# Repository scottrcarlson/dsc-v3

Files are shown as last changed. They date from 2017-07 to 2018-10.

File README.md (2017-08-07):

# DSCv3

[What is Dirt Simple Comms (DSC) ?]
------------------

[Goals]
----------------
 1. To not require existing infrastructure
 2. To operate well and propage messages in poor rf environments.
 3. To securely exchange messages with friends in hostile rf environments. 
 4. To avoid central points of control in the system design.
 5. To keep the attack surface as small as possible.
 6. Make it easy to use and hard to mess up.
 7. To leak as little data as possible.
 8. Low Cost / Low Power / Long Range
 9. Small Form Factor / Portable
 10. Utilize LoRA Modulated 900mhz Radio System

[Bill of Materials]
------------------
(Work in Progress)
(Prices can be optimized based on source and quantity)
Total Estimated price $85-$120)

* $5 RPi Zero (Wherever you can get one)
* $13 DS3231 Precision RTC https://www.adafruit.com/product/3013
* $33 LL-RXR-27 LoRa Transceiver http://www.futureelectronics.com/en/Technologies/Product.aspx?ProductID=LLRXR27915SYMALINKLABS5062354&IM=0
* $23 OLED Bonnet https://www.digikey.com/products/en?mpart=3531&v=1528
* $3 SMA to u.Fl Adapter Cable https://www.amazon.com/2pcs-Female-Pigtail-Hirose-0-81mm/dp/B00UTT8842
* $13 Antenna 1/2 Wave 5dBi https://www.amazon.com/TECHTOO-700-2600Mhz-Directional-Connector-Wireless/dp/B00VV63WEI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
* OR
* $7 Antenna 1/2 Wave 5dBi https://www.amazon.com/915Mhz-antenna-direction-folding-Shipping/dp/B072QB7LRJ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
* RGB Led (tbd)
* Vibration (Disc Motor) (tbd)
* LiPo 2200mAh https://www.adafruit.com/product/328
* LiPo Charging/Switchover https://www.adafruit.com/product/1944

[Assembly / Wiring]
------------------

[Configuring Vanilla Raspian]
------------------

[Install DSCv3 Software]
------------------

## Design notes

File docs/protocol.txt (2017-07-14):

Dirt Simple Comms v2 (DSCv2) Messaging Device Description

[Table of Contents]
-------------------
 *- Goals
 *- Basic Description of Operation
 *- Facts
 *- Key Generation, Management and Exchange
 *- Authentication / Data Storage 
 *- Protocol Description: Messages
 *- Protocol Description: Beacons
 *- Future Work

[Goals]
----------------
 1. To not require existing infrastructure
 2. To operate well and propage messages in poor rf environments.
 3. To securely exchange messages with friends in hostile rf environments. 
 4. To avoid central points of control in the system design.
 5. To keep the attack surface as small as possible.
 6. Make it easy to use and hard to mess up.
 7. To leak as little data as possible.
 8. Low Cost / Low Power / Long Range
 9. Small Form Factor / Portable
 10. Utilize LoRA Modulated 900mhz Radio System

[Basic Description of Operation]
--------------------------------
A group of friends meet on location (camping, festivals, conferences, etc). Each person
produces their dscv2 module and generates two pairs of keys (encryption / signature keys) 
and exchanges their public keys physically (currently via USB).

The network is manually configured for fixed/static TDMA operation.

Now friends can freely exchange messages with each other. Every node acts as a repeater.
Every message gets repeated by all nodes. It is a blind broadcast. There is no routing
information or packet headers. All data is encrypted and then signed before transmission.
The idea is for all msgs to eventually get to where they are destined without sharing
too much meta data. 

If Alice wants to send a msg to Bob and they are not currently within range, other nodes 
that are may then receive the message, verify its signature and then begin repeating, 
eventually Bob receives his message.

All nodes will periodically broadcast a beacon, which is comprised of a cleartext hash that
is signed. 

Beacons Provide:
1. Signature
2. Repeat List Hash (Additional state info (EMPTY/QUIET)
3. Stats (Last seen, RSSI and SNR) <-- Indirectly

As the messages begin to pile up in each of the nodes repeat buffers, you can imagine the
network becomes more lethargic. To mitigate this an additional piece of information is
sent with the beacon. A hash of all msgs in the repeat buffer.

Each node tracks the last received beacon hash of its neighbors. If the hash is equal to
the current node, then a confidence counter is incremented. If all neighbors have a high level
of confidence (that everybody has everything), then the node will transition into a /quiet mode/.

Quiet mode prevents any further transmission of messages. It also increases the frequency of
beacon broadcasts. When in quiet mode, a special hash(quiet hash) is used. If a neighboring node
receives this quiet hash it will force that node into quiet mode as well. Quiet mode should 
propogate to all nodes. When all nodes exist the quiet mode period (typically 2 TDMA cycles),
the network is reset with empty repeat buffers.

Rinse, Repeat and Msg.

This system may shine at locations where there is no cellular service, or hostile actors 
running rampant over the rf spectrum.

[Facts]
--------------
1. A node can only know for certain that a msg is/or is NOT for them. Not whom it is destined.
2. A node can know the origination of a message (based on its signature)
3. A node can NOT know if a specific msg has arrived at its destination.
4. A node can know if EVERYONE has EVERYTHING. (Hence knowing a message has arrived at its dest)
5. A node will drop any packet that is not signed by its peers.

[Key Generation, Management and Exchange]
-----------------------------------------
 Key Generation Process Consists:
     1. Create Keychains
     2. Generating Pub/Priv Encyption Keys
     3. Generating Pub/Priv Signature Keys
     4. Encrypt each keychain with a randomly generated passphrase
     5. Store passphrases on yubikey/usb drive.
     ** Plans to move to U2F dongles, no static passwords!!

The public keys are then copied to every node on the network. Currently a valid signature
is required for a node to repeat a message. In this case we need to exchange 2*(n-1) keys 
to function properly. There is also a weakness as the origination of a msg is known to all. 
(But not the destination!) 

The keys are currently transferred on physical medium (usb drive), but should ultimately
be able to exchange over the air. 

[Authentication / Data Storage]
-------------------------------
All data is encrypted on disk. Cleartext only resides in memory. To authenticate
is to unencrypt the node's keychain. This happens by plugging in the yubikey device and long
pressing the button (which feeds a passphrase). If the correct yubikey is inserted, 
the keychain unlocks, and the current message threads are decrypted and ready for viewing. 
Once the key is removed, the screen locks, and memory is wiped. The system is now at rest. 
It is unable to decrypt or sign msgs. If physically stolen, no message data is available.

[Protocol Description]
------------------------------
Fixed TDMA stategy is used. Each node needs to be manually configured ahead of time.
The following settings are configurable:
    1. TDMA Slot Number
    2. Total Number of Nodes
    3. TX Time
    4. Deadband Time
Where the TDMA Slot Width = TX Time + Deadband Time

** Messages
----------
The cleartext max size is 150bytes (<-- what is the actual number)

Encypting and then signing the cleartext yields:

   cypher    signature
|[261 bytes][261 bytes]|

    * 255 bytes due to pkcs11 padding and 2048 bit key
    * 6 bytes are overhead from Keyczar library implementation. (***add details)

The total data packet size 522 bytes exceeds max rf packet size of 255 bytes. 

We must split the packet into 3 segments, and send them OTA individually:

   cipher    signature           Seg1          Seg2          Seg3
|[261 bytes][261 bytes]| --> |[255 bytes]| |[255 bytes]| |[12 bytes]|

The last 6 bytes of the cipher block get shifted into the beginning of the signature
block, the last 12 bytes of the signature block shifts into the third segment.

To help the packets get reassembled properly on the other end, the first 100 bytes 
are copied from Seg1 and Seg2 and appended to the third segment. The third segment will 
be called the fingerprint. (**is there a standard term for this)

    Seg1          Seg2       Fingerprint
|[255 bytes]| |[255 bytes]| |[212 bytes]|

Upon receiving each segment, the node will accumulate them into a temporary 
buffer that gets cleared periodically (to mitigate spam and orphan segments).
To reassemble we look for segments that are 212 bytes, and then use the two 100byte 
segments to search for the remaining subpackets in the buffer.
Once found and reassembled it removes the segments from the buffer and 
attempts to verify the signature of the complete packet.

Once the packet signature has been verfied, it is then added to the repeat buffer 
to be retransmitted to other nodes. If the node is /unlocked/ it will then attempt to
decrypt the packet. Upon success it is then further processed for viewing/storage.

Duplicate Segments and Messages are Dropped. Unsigned Packets get Dropped.

** BEACONS
----------
Beacon messages will play a large role in the health of the network. By exchanging state
information, each node can determine when all neighbors have all information. A beacon
is sent at the beginning of a nodes TDMA window.

Beacon Message:

   hash     signature
|[32 bytes][261 bytes]|

The repeat buffer of each node is hashed before transmitting the beacon. 

Each node tracks the state of its neighbors. When their hashes match a confidence counter
increments. Once any single node has a high confidence count on every node, a consensus
is made. (First to discover, Everyone has everything). The consensus triggers /Quiet/
mode. 

/Quiet/ mode prevents transmission of messages for a period of time. During this period of
time it sends a beacon continuously within its tdma slot.
The beacon contains a /Quiet/ hash, telling the other
nodes that it has decided that everyone has everything and therefore force peer nodes that 
receive this packet to also go into quiet mode. This mode propogates throughout the network,
and at the end of quiet mode the repeat list is cleared, and the system starts fresh.
** Note current issues. Race conditions....

[Future Work]
-------------
1. How to mitigate the damage a compromised node can do to a network.
	(spam/garbage with proper signature, breaking tdma transmit ediquite)
2. Rethink Keys / Key Exchange / Crypto. Try to make it simpler to use and to allow
	more features, such as forward secrecy, future secrecy, key exchange OTA,
	symettric network session keys to allow for sending one to many without sending n-1
	individually encrypted msgs.
3. Encrypt/Sign Beacons (Currently the beacon is cleartext + sig)
4. Dynamic TDMA (Adding/Removing Nodes, optimizing slot cycles based on presence)
5. Explore physical device hardening. (Tamper evident, Self Destruct, Proper Memory Handling,
	Trusted Computing)
6. External IC for RNG
7. Smaller formfactor / better UX
8. Replace static storage of keychain passphrase with decentralized U2F hardware key.

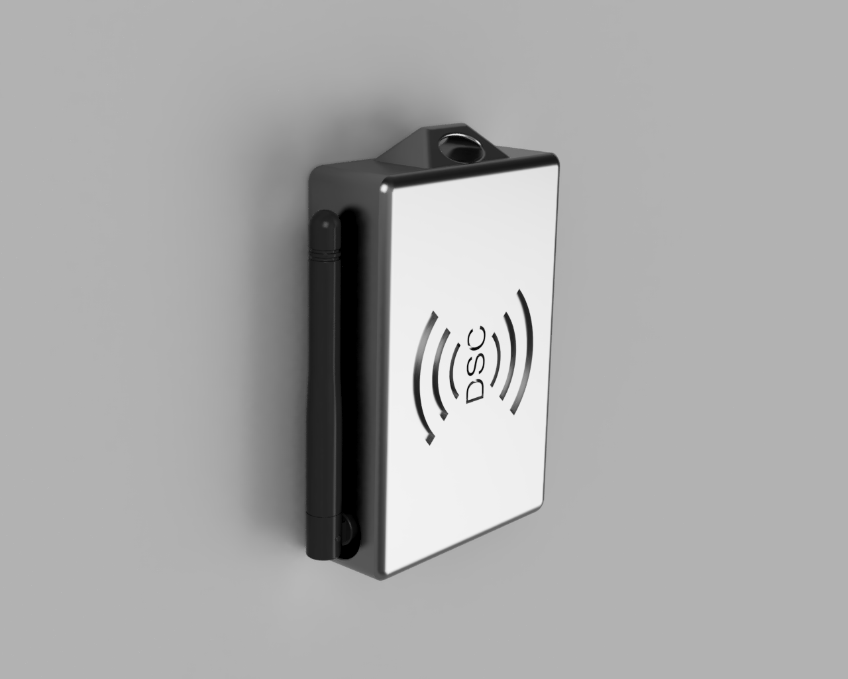
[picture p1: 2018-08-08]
enclosure/87cbd582-e5d6-46ba-be8c-0ddc85d05ea8.PNG

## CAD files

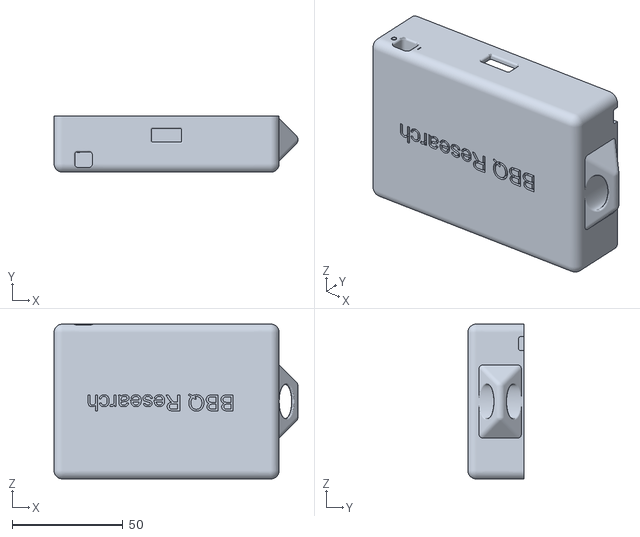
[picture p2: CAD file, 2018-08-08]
enclosure/Case.obj
110.1 x 25.4 x 69.8

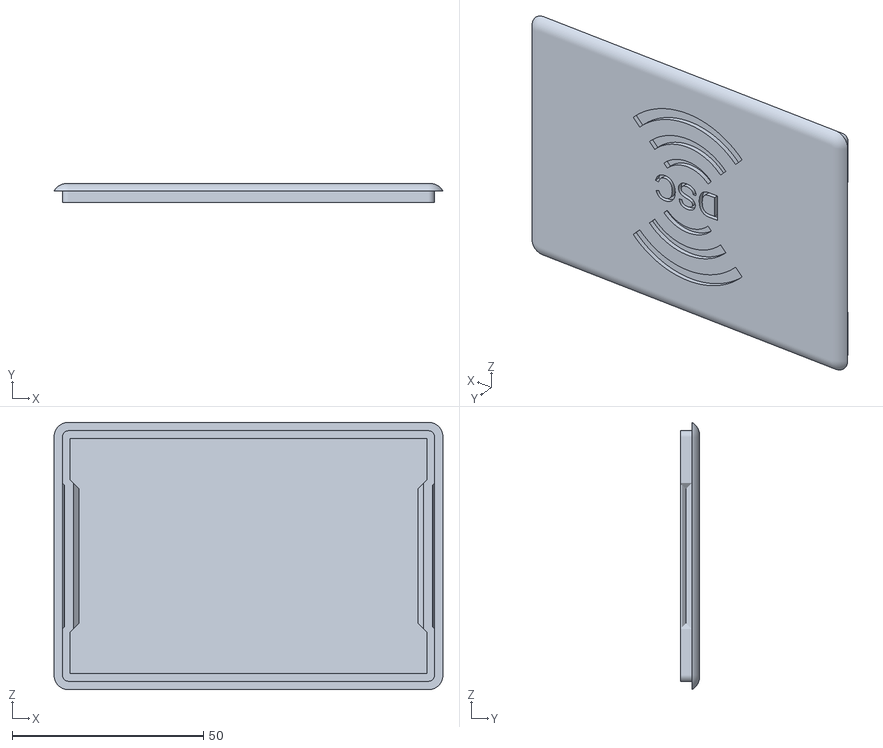
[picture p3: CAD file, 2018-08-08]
enclosure/TopCover.obj
101.6 x 5.00 x 69.8

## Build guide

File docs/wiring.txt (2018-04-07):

# Wiring and Assembly Documentation for DSC v3

Pre-Assembly
1. Make Micro USB Harness Cable
2. Wire Leads onto
	- RTC
	- RADIO
	- POWER BOARD + Power Switch
	- RGB LED
	- MOTOR and Driver
	- Tilt Sensor
3. Soldier Header to PI Zero
3. Wire RTC to PI
4. Wire Power Board to PI
5. Wire Radio to PI
6. Power on Test. Check for OLED+RTC+Radio+Power functionality
7. Wire RGB Led to PI
8. Wire Tilt Sensor to PI
9. Wire Motor/Driver to PI
10. Full System Test (Power on and test all components)

Final Assembly
1. Place Power Switch and Glue
2. Place Motor and Glue
3. Place USB a Female jack and Glue
4. Place RGB Led
5. Slide Pi+OLED Into Slot
6. Place Power Board in Slot
7. Place Radio In Slot
8. Find a Spot for the tilt sensor
9. Place RTC (w RTC Battery) into slot
10. Final Power On Test
11. Arrange Wires so they do not interfere with cap
12. Engage Cap
13. Engage Bezel and Button Caps

Raspberry Pi Zero
*Board Pin Numbers Used
-------------------------------------
PIN 38  (I)  --> Radio IRQ
PIN 40 (O)  --> Radio Reset
PIN 11 (O)  --> OLED Reset
PIN 33 (I)  --> Key Up
PIN 15 (I)  --> Key Down
PIN 13 (I)  --> Key Left
PIN 16 (I)  --> Key Right
PIN 31 (I)  --> Key Enter
PIN 29 (I)  --> Key Back
PIN 7  (I)  --> Key Extra
PIN 8  (TX) --> Radio RX)
PIN 10 (RX) --> Radio TX)
PIN 3  (I2C SDA) --> SDA (OLED / RTC)
PIN 5  (I2C SCL) --> SCL (OLED / RTC)
PIN 37 (I) --> Low Battery
PIN 32 (I) --> Tilt Sensor
PIN 18 (O) --> Vibration Motor
PIN 33 (O) --> Red Status LED
PIN 36 (O) --> Green Status LED
PIN 35 (O) --> Blue Status LED
PIN 1, 17 --> 3v3 (Used to Power Radio and RTC)
PIN GND   --> Ground all Components
--------------------------------------

POWER BOARD (PowerBoost 500 Charger)
---------------
EN      --> Power Switch 
GND     --> Power Switch
LB      --> Low Battery (PI PIN 37) [length: 3.5in]
VCC out --> 5v VCC (PI PIN 2)       [length: 3.3in] 26AWG
GND     --> (PI PIN 6)              [length: 3.3in] 26AWG
---------------

TILT SWITCH
---------------
LEG1 --> PI GPIO 32	[length: 2 in]
LEG2 --> PI GND 30  [""]
---------------

POWER SWITCH
---------------
LEG1 --> POWER BOARD (EN PIN) [length: 2.2 in]
LEG2 --> POWER BOARD (GND)	  [""]
---------------

uUSB to USBA Female Harness
---------------
5v  uUSB --> 5v USB A  [length: 2.5in]
GND uUSB --> GND USB A [""]
D+  uUSB --> D+ USB A  [""]
D-  uUSB --> D- USB A  [""]
---------------

VIBRATING MOTOR
*rough notes for wire lengths (dead pin style)
extend motor leads by 2.5in
---------------
MOT+          --> PI PIN 4
MOT-          --> NPN Collector
DIODE         --> FROM MOT+ to MOT-
NPN_BASE 	  --> Resistor 220ohm --> PI PIN 18
NPN_COLLECTOR --> PI PIN 20
---------------

RGB LED
*Series Resistor Sized to allow each LED to draw approx 2.5mA
---------------
CATHODE --> PI PIN 39 							 [length: 3.5 in]
R_ANODE --> PI GPIO 33 (Series Resistor 470ohms) [""]
G_ANODE --> PI GPIO 36 (Series Resistor 220ohms) [""]
B_ANODE --> PI GPIO 35 (Series Resistor 220ohms) [""]
---------------

RTC
---------------
SDA --> (Pi Zero PIN 3) [length: 2.5 in] * I think this can be shortened
SCL --> (Pi Zero PIN 5) [""]
3v3 --> (Pi Zero PIN 1) [""]
GND --> (Pi Zero PIN 9) [""]
---------------

RADIO
---------------
PIN 5  (3v3)   --> (Pi Zero PIN 17) [length: 3.6 in]
PIN 25 (GND)   --> (Pi Zero PIN 14) [length: 3.5 in]
PIN 23 (RX)    --> (Pi Zero PIN 8)  [length: 3.5 in]
PIN 24 (TX)    --> (Pi Zero PIN 10) [length: 3.5 in]
PIN 7  (Reset) --> (Pi Zero PIN 40) [length: 3.5 in]
PIN 8  (IRQ)   --> (Pi Zero PIN 38) [length: 3.6 in] 
---------------

# Reference: Raspberry Pi Zero and LL-RXR-27 radio 
Pinout Diagrams: https://docs.google.com/document/d/1CCm--WU$

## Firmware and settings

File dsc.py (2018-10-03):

#!/usr/bin/python
# ---------------------------------------
# --- Dirt Simple Comms DSCv3 MAIN Thread
# ----------------------------------------
import signal
import logging
import Queue
import RPi.GPIO as GPIO
from time import sleep
import time
import iodef

from message import Message
from crypto import Crypto
from radio import Radio
from display import Display
from ui import UI
from gps import Gps
from config import Config

version = "v0.5.0"
revision = "?"              # grab this from git
isRunning = True            # Main Thread Control Bit

radio = None
display = None
ui = None

heartbeat_ui = Queue.Queue()
heartbeat_display = Queue.Queue()
heartbeat_radio = Queue.Queue()
heartbeat_message = Queue.Queue()


def signal_handler(signal, frame):  # nicely shut things down
    quitdsc()


def quitdsc():
    log.info("DSC received shutdown signal")
    radio.stop()
    gps.stop()
    message.test_message_file.close()
    message.stop()

    if config.hw_rev < 3:
        ui.stop()
        display.stop()
    global isRunning

    isRunning = False


if __name__ == "__main__":
    log = logging.getLogger()
    log.setLevel(logging.DEBUG)

    fh = logging.FileHandler('/dscdata/dsc.log')
    ch = logging.StreamHandler()
    fh.setLevel(logging.DEBUG)
    ch.setLevel(logging.DEBUG)

    formatter = logging.Formatter('%(asctime)s| %(module)-12s| %(levelname)-8s| %(message)s')
    fh.setFormatter(formatter)
    formatter = logging.Formatter('%(asctime)s| %(module)-12s| %(levelname)-8s| %(message)s')
    ch.setFormatter(formatter)

    log.addHandler(fh)
    log.addHandler(ch)

    logging.getLogger("ll_ifc").setLevel(logging.WARNING)

    log.info('+----------------------------+')
    log.info("+ Dirt Simple Comms 4 " + version)
    log.info('+----------------------------+')


    # log.debug("hg rev: " + revision)
  
    config = Config()
    log.info("HW Rev: " + str(config.hw_rev))
    log.debug("Node UID: " + config.node_uuid)
    iodef.init()

    if config.hw_rev >= 3:
        import ble
        import ble_gatt_dsc as ble_gatt
        ble.init_ble()

    crypto = Crypto()

    message = Message(crypto, config, heartbeat_message)
    message.start()

    radio = Radio("/dev/serial0", config, message, heartbeat_radio)
    radio.start()

    gps = Gps()
    gps.start()

    if config.hw_rev < 3:
        display = Display(message, version, config, revision, heartbeat_display)
        display.start()

        ui = UI(display, message, crypto, radio, config, heartbeat_ui)
        ui.start()
        ui.splash()

    if config.hw_rev >= 3:
        dscGatt = ble_gatt.DscGatt(quitdsc, message, config, radio)
        dscGatt.start()

    """
    GPIO.output(iodef.PIN_MOTOR_VIBE, True)
    sleep(0.3)
    GPIO.output(iodef.PIN_MOTOR_VIBE, False)
    sleep(0.1)
    GPIO.output(iodef.PIN_MOTOR_VIBE, True)
    sleep(0.3)
        GPIO.output(iodef.PIN_MOTOR_VIBE, False)
    """
    heartbeat_time = time.time()

    for sig in (signal.SIGABRT, signal.SIGINT, signal.SIGTERM):
        signal.signal(sig, signal_handler)

    while isRunning:
        try:
            if time.time() - heartbeat_time > 30:
                heartbeat_time = time.time()

                if not GPIO.input(iodef.PIN_NOT_LOW_BATT):
                    log.info("Low Battery")
                    log.info("Shutting the system down in 60 seconds.")
                    # Shutdown timer --> do it

                # if GPIO.input(iodef.PIN_TILT):
                #    log.info("Tilted.")
                # else:
                #    log.info("Not Tilted.")
                if config.hw_rev < 3:
                    try:
                        packet = heartbeat_ui.get_nowait()
                    except Queue.Empty:  # Thread possibly dead, start re-covery timer and log
                        log.error("UI Thread seems to be dead.")
                    try:
                        packet = heartbeat_display.get_nowait()
                    except Queue.Empty:  # Thread possibly dead, start re-covery timer and log
                        log.error("Display Thread seems to be dead.")
                try:
                    packet = heartbeat_radio.get_nowait()
                except Queue.Empty:  # Thread possibly dead, start re-covery timer and log
                    log.error("Radio Thread seems to be dead.")
                try:
                    packet = heartbeat_message.get_nowait()
                except Queue.Empty:  # Thread possibly dead, start re-covery timer and log
                    log.error("Message Thread seems to be dead.")

            elif time.time() - heartbeat_time < 0:
                    log.warn("Time changed to past. Re-initializing.")
                    heartbeat_time = time.time()
        except Exception as e:
                log.error(str(e))
        sleep(5)
    iodef.PWM_LED_RED.stop()
    iodef.PWM_LED_GREEN.stop()
    iodef.PWM_LED_BLUE.stop()

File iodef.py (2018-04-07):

#!/usr/bin/python
# ----------------------------
# --- DSC2 IO Handler
#----------------------------
import RPi.GPIO as GPIO

# Pin Definitions

# Reference: Raspberry Pi Zero and LL-RXR-27 radio Pinout Diagrams: https://docs.google.com/document/d/1CCm--WU5d0TojT0b95wAke5KnvuqtFVSWwcs-sNXcJo
# Pins 3 and 5 are used for I2C communication with the OLED and RTC
# Pins 8 and 10 are used for serial communication with the radio

  
PIN_KEY_ENTER   = 31 #B
PIN_KEY_LEFT    = 13
PIN_KEY_RIGHT   = 16
PIN_KEY_UP      = 11
PIN_KEY_DOWN    = 15
PIN_KEY_BACK    = 29 #A
PIN_KEY_EXTRA   = 7  #Center
PIN_RADIO_IRQ   = 38
PIN_RADIO_RESET = 40
PIN_NOT_LOW_BATT = 37
PIN_LED_RED = 33
PIN_LED_GREEN = 36
PIN_LED_BLUE = 35
PIN_TILT = 32
PIN_MOTOR_VIBE = 18

PWM_LED_RED = None
PWM_LED_GREEN = None
PWM_LED_BLUE = None


def init():
    global PWM_LED_RED
    global PWM_LED_GREEN
    global PWM_LED_BLUE

    GPIO.setwarnings(False)
    GPIO.setmode(GPIO.BOARD)
    
    GPIO.setup(PIN_RADIO_IRQ, GPIO.IN, pull_up_down=GPIO.PUD_DOWN)
    GPIO.setup(PIN_RADIO_RESET, GPIO.OUT)    
    GPIO.setup(PIN_KEY_ENTER, GPIO.IN, pull_up_down=GPIO.PUD_UP)
    GPIO.setup(PIN_KEY_BACK, GPIO.IN, pull_up_down=GPIO.PUD_UP)
    GPIO.setup(PIN_KEY_UP, GPIO.IN, pull_up_down=GPIO.PUD_UP)
    GPIO.setup(PIN_KEY_DOWN, GPIO.IN, pull_up_down=GPIO.PUD_UP)
    GPIO.setup(PIN_KEY_LEFT, GPIO.IN, pull_up_down=GPIO.PUD_UP)
    GPIO.setup(PIN_KEY_RIGHT, GPIO.IN, pull_up_down=GPIO.PUD_UP)


    GPIO.setup(PIN_TILT, GPIO.IN, pull_up_down=GPIO.PUD_UP)
    GPIO.setup(PIN_NOT_LOW_BATT, GPIO.IN, pull_up_down=GPIO.PUD_UP)

    GPIO.setup(PIN_MOTOR_VIBE, GPIO.OUT) 
    GPIO.setup(PIN_LED_RED, GPIO.OUT) 
    GPIO.setup(PIN_LED_GREEN, GPIO.OUT) 
    GPIO.setup(PIN_LED_BLUE, GPIO.OUT) 

    GPIO.output(PIN_LED_RED, False)
    GPIO.output(PIN_LED_GREEN, False)
    GPIO.output(PIN_LED_BLUE, False)  

    PWM_LED_RED = GPIO.PWM(PIN_LED_RED, 100)
    PWM_LED_GREEN = GPIO.PWM(PIN_LED_GREEN, 100)
    PWM_LED_BLUE = GPIO.PWM(PIN_LED_BLUE, 100)
    PWM_LED_RED.start(0)
    PWM_LED_GREEN.start(0)
    PWM_LED_BLUE.start(0)

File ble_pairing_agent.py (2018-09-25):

#!/usr/bin/python

from sh import btmgmt
import json
import dbus
import dbus.service
import dbus.mainloop.glib
try:
	from gi.repository import GObject
except ImportError:
	import gobject as GObject
import signal

BUS_NAME = 'org.bluez'
AGENT_INTERFACE = 'org.bluez.Agent1'
AGENT_PATH = "/test/agent"

bus = None
device_obj = None
dev_path = None
mainloop = None

CMD_INIT = "init"
CMD_ADVERTISE_ON = "advertise_on"
CMD_ADVERTISE_OFF = "advertise_off"
CMD_PAIRING_ON = "pairing_on"
CMD_PAIRING_OFF = "pairing_off"
CMD_CLEAR_DEVICES = "clear_devices"
CMD_PAIR_ACCEPT = "pair_accept"
CMD_PAIR_REJECT = "pair_reject"


def build_pair_req_msg(addr, passkey):
	msg = {}
	msg['addr'] = addr
	msg['passkey'] = passkey
	return json.dumps(msg)


def init_dsc_ble():
	btmgmt.power.off()
	btmgmt.connectable.on()
	btmgmt.bondable.on()
	btmgmt.pairable.on()
	btmgmt.le.on()
	btmgmt.bredr.off()
	btmgmt.linksec.off()
	btmgmt.ssp.off()
	btmgmt.sc.on()
	btmgmt.privacy.off()
	btmgmt.advertising.on()

	btmgmt("io-cap", "0x04")  # DisplayKeyboard (for Numeric Comparison type pairing)
	btmgmt.power.on()


def get_device_info():
	info = btmgmt.info()
	info_lines = info.split("\n")

	results = {}
	results['interface'] = info_lines[1].split(':')[0]
	results['address'] = info_lines[2].split(' ')[1]
	results['settings'] = info_lines[4].split(':')[1]
	results['name'] = info_lines[5].split(' ')[1]
	results['alias'] = info_lines[6].split(' ')[1]
	return results


def ask(prompt):
	try:
		return raw_input(prompt)
	except Exception:
		return input(prompt)


def set_trusted(path):
	props = dbus.Interface(bus.get_object("org.bluez", path), "org.freedesktop.DBus.Properties")
	props.Set("org.bluez.Device1", "Trusted", True)


def dev_connect(path):
	dev = dbus.Interface(bus.get_object("org.bluez", path), "org.bluez.Device1")
	dev.Connect()


class Rejected(dbus.DBusException):
	_dbus_error_name = "org.bluez.Error.Rejected"


class Agent(dbus.service.Object):
	exit_on_release = True

	def set_exit_on_release(self, exit_on_release):
		self.exit_on_release = exit_on_release

	@dbus.service.method(AGENT_INTERFACE, in_signature="", out_signature="")
	def Release(self):
		print("Release")
		if self.exit_on_release:
			mainloop.quit()

	@dbus.service.method(AGENT_INTERFACE, in_signature="os", out_signature="")
	def AuthorizeService(self, device, uuid):
		print("AuthorizeService (%s, %s)" % (device, uuid))
		authorize = ask("Authorize connection (yes/no): ")
		if (authorize == "yes"):
			return
		raise Rejected("Connection rejected by user")

	@dbus.service.method(AGENT_INTERFACE, in_signature="o", out_signature="s")
	def RequestPinCode(self, device):
		print("RequestPinCode (%s)" % (device))
		set_trusted(device)
		return ask("Enter PIN Code: ")

	@dbus.service.method(AGENT_INTERFACE, in_signature="o", out_signature="u")
	def RequestPasskey(self, device):
		print("RequestPasskey (%s)" % (device))
		set_trusted(device)
		passkey = ask("Enter passkey: ")
		return dbus.UInt32(passkey)

	@dbus.service.method(AGENT_INTERFACE, in_signature="ouq", out_signature="")
	def DisplayPasskey(self, device, passkey, entered):
		print("DisplayPasskey (%s, %06u entered %u)" %
								(device, passkey, entered))

	@dbus.service.method(AGENT_INTERFACE, in_signature="os", out_signature="")
	def DisplayPinCode(self, device, pincode):
		print("DisplayPinCode (%s, %s)" % (device, pincode))

	@dbus.service.method(AGENT_INTERFACE, in_signature="ou", out_signature="")
	def RequestConfirmation(self, device, passkey):
		print("RequestConfirmation (%s, %06d)" % (device, passkey))
		print build_pair_req_msg(device, passkey)
		confirm = ask("Confirm passkey (yes/no): ")
		if (confirm == "yes"):
			pair_reply(device)
			return
		raise Rejected("Passkey doesn't match")

	@dbus.service.method(AGENT_INTERFACE, in_signature="o", out_signature="")
	def RequestAuthorization(self, device):
		print("RequestAuthorization (%s)" % (device))
		auth = ask("Authorize? (yes/no): ")
		if (auth == "yes"):
			return
		raise Rejected("Pairing rejected")


	@dbus.service.method(AGENT_INTERFACE, in_signature="", out_signature="")
	def Cancel(self):
		print("Cancel")


def pair_reply(device):
	set_trusted(device)
	print("Device paired")
	mainloop.quit()


def pair_error(error):
	err_name = error.get_dbus_name()
	if err_name == "org.freedesktop.DBus.Error.NoReply" and device_obj:
		print("Timed out. Cancelling pairing")
		device_obj.CancelPairing()
	else:
		print("Creating device failed: %s" % (error))
	mainloop.quit()


if __name__ == '__main__':
	signal.signal(signal.SIGINT, signal.SIG_DFL)

	dbus.mainloop.glib.DBusGMainLoop(set_as_default=True)
	bus = dbus.SystemBus()

	capability = "KeyboardDisplay"
	path = "/test/agent"
	agent = Agent(bus, path)

	mainloop = GObject.MainLoop()
	obj = bus.get_object(BUS_NAME, "/org/bluez")
	manager = dbus.Interface(obj, "org.bluez.AgentManager1")
	manager.RegisterAgent(path, capability)
	manager.RequestDefaultAgent(path)
	print("DSC BLE Pairing Agent Active.")

	init_dsc_ble()
	print("DSC BLE Interface Configured and Active.")
	print get_device_info()
	address = get_device_info()['address']
	print("DSC MAC: [" + address + "]")
	print("Waiting for pair request...")
	try:
		mainloop.run()
	except KeyboardInterrupt:
		btmgmt.bondable.off()

	print("Exit. DSC is not Bondable.")
	# btmgmt.bondable.off()
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

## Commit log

2017-07-14 replace assymetric crypto (keyczar module) w/ symmetric (cryptography module)
    [crypto.py]
2017-07-15 Fixed last few bugs from code overhaul, new msg protocol/crypto fully functional
    [message.py]
2017-07-21 Messaging bugs, corrected msg list bug, cleaned up some dead wood
    [message.py]
2017-08-01 Commiting changes from Defcon bug crushing sessions.
    [config.py, crypto.py, display.py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]
2017-08-02 Added Lock screen. UI Bug fixes.
    [display.py, dsc2.py, gps.py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]
2017-08-02 Added Airplane Mode. Fixed/Smoothed some UI Issues.
    [config.py, crypto.py, display.py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]
2017-08-04 Bill of Materials (First Pass)
2017-08-06 Fixing up GPS reporting.
    [dsc2.py, gps.py, ui.py]
2017-08-07 House keeping, removed old v2 hardware design files
    [DSC_IO_Board.brd, DSC_IO_Board.sch, dscv2_enclosure_bot.stl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]
2017-08-07 Update README.md
    Updating BOM
2017-08-07 Hotplug GPS / Exposing Stats / Log when fixed.
    [gps.py]
2018-04-07 Improved gps device handling.
2018-04-07 DSCv3 wiring list/lengths
2018-04-07 Added motor vibration on msg receipt. cleaned up logging.
    [message.py]
2018-04-07 Added RX/TX/Beacon LED indication
2018-04-07 Stubbed Low Battery Handler.
2018-07-27 Carving out support for DSCv4 (BLE Outboarding Mode) There is an accompanying Android application. Bringing in BLE/GATT Services Re-arrange / Modifications to support DSCv3 and DSCv4 modes.
    BLE Gatt Settings Service fully functional. Persist to Radio/Disk. Syncronize from Android device.
    BLE Gatt Datetime Sync Service. The new units do not have an RTC, we rely on handset to push/sync date and time.
2018-08-08 Detaching system configuration from original display/ui, to support handset via ble
    [Case.obj, TopCover.obj]
2018-09-01 fixed tdma frame calculations that were only done at startup, now will re-calculate when a network parameter has changed.
    Testing units shows perfect tdma schedules now.
    [radio.py]
2018-09-02 Implemented center frequency hopping sequence. This sequence will be called a "virtual channel"
    The sequence takes the secret+epoch to seed the PRNG.
    That seed will be used once per tdma frame start to generate the center frequency to use.
2018-09-23 Remove Radio Interrupt Channel. This has caused so many ansyncronous related issues. Reading and writing to the radio modules's serial channel is now don syncronously.
    Transmission rate is limited by tx_throttle but can be removed once more computationally expense operations are optimized in adjacent message thread.
    Continuing to add in virtual channel support with individual p2p channels for rapid exchange of information.
    [radio.py]
2018-09-25 Batching Acknowledgment messages. Linting.
    Prototyping chacha20/poly1305, to replace AES.
    Including small ncurses based chat mockup from Tyler. This would be really cool
    to use in serial gadget mode on the pi.
    [ble.py, ble_gatt_base.py, ble_gatt_dsc.py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]
2018-10-03 Fixes and optimization to the protocol.
    [ble_gatt_dsc.py, crypto.py, dsc.py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]
2018-10-20 House keeping
    prepping to replace aes
    [ble.py, config.py, crypto.py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]
2018-10-21 Replaced AES with ChaCha20 Poly1305 AEAD mode.
    [crypto.py]
